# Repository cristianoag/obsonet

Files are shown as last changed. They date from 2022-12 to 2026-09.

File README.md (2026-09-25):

# Obsonet Reloaded
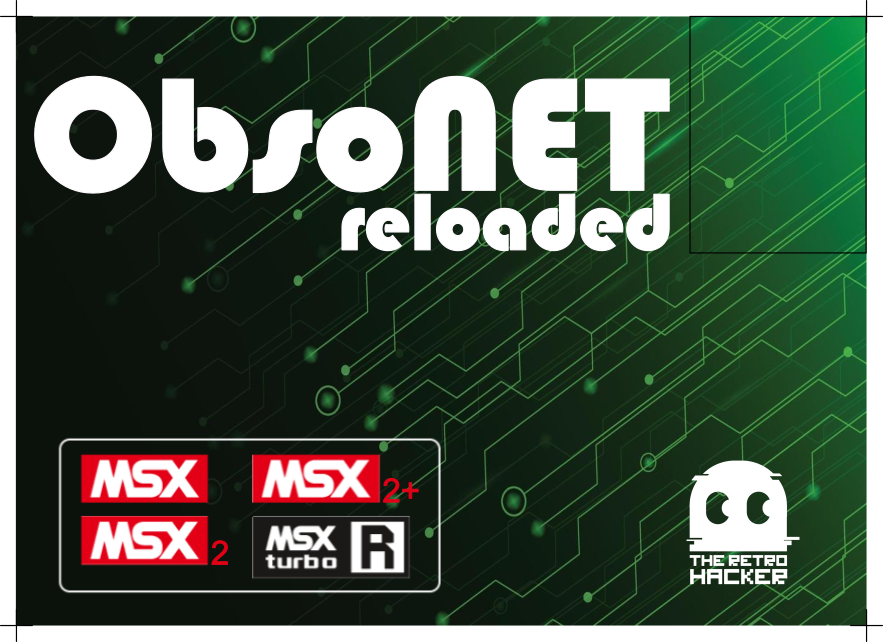
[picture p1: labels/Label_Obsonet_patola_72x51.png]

This is the GitHub repository to host all source files for the Obsonet Reloaded. 

The ObsoNET is the first network card created for the MSX. In 2004, the hardware designer Daniel Berdugo and software developer Nestor Soriano joined forces to create a cartridge to bring ETHERNET standard to the MSX line of computers. 

The cartridge is based on the Realtek RTL8019AS chip and uses a flash memory to host and execute a BIOS that allows the use of network commands from the Nextor operating system (compatible with MSXDOS). An EPROM stores basic configuration data for the RTL8019AS chip and a side connector is used to plug a network cable to your MSX. A GAL16VB is used to implement the logic required to activate and expose the cartridge to the computer.

The original version of the Obsonet was designed to fit a standard Konami cartridge case. The goal of this project is to create a new version of the cartridge that fits the standard Patola cartridge case available in Brazil as well as the standard Konami cases available from multiple vendors WW.

## Hardware 

### PCB

The files required to build the original version of the Obsonet are available [https://github.com/msx-solis/obsonet](here). You can download the gerber files and order from any PCB manufacturer.

I have created another version of the PCB that I called Obsonet Reloaded. The goal was to have the board fitting the standard Patola cartridge cases available in Brazil as well as the standard Konami cases available from multiple vendors WW.

|Front Side|Back Side|
|---|---|
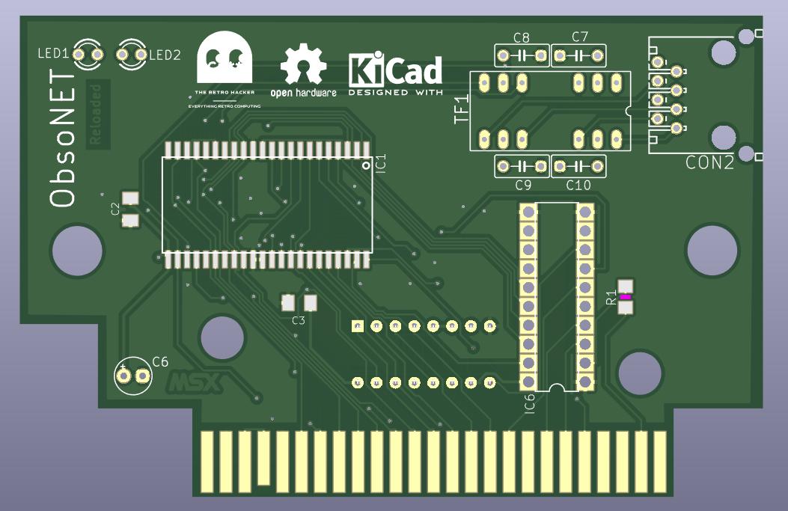
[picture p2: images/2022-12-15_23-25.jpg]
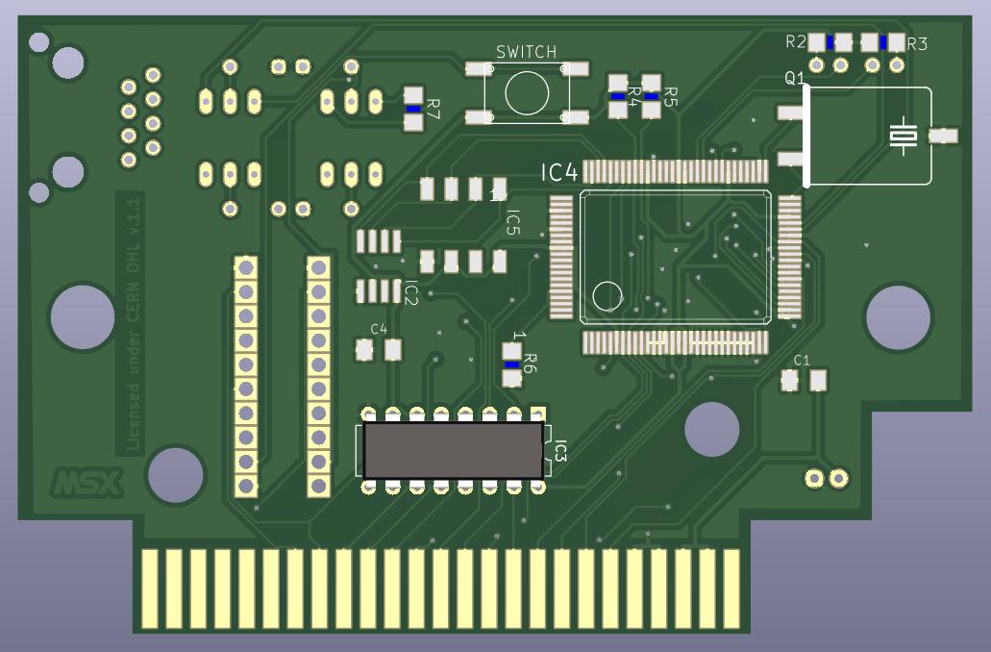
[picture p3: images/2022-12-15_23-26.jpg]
|||
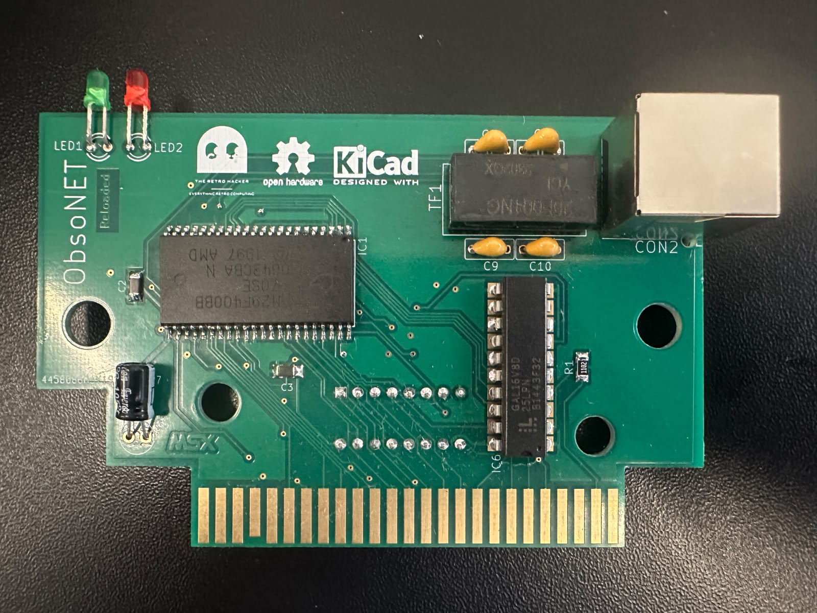
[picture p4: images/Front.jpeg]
Front
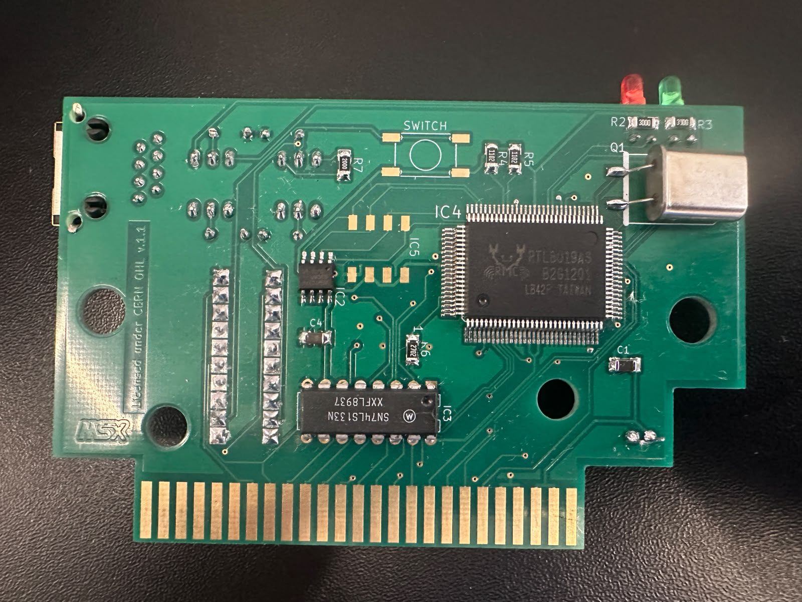
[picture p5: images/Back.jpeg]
Back
|||

### Bill of Materials

[Obsonet Reloaded Interactive BOM](https://htmlpreview.github.io/?https://github.com/cristianoag/obsonet/blob/main/hardware/bom/ibom.html)

| Reference | Value | Description | Package | Qtd | Link |
|---|---|---|---|-----|---|
| C1-C4 | 100nF | C-EUC1206K | C1206 | 4 | [Ali Express](https://s.click.aliexpress.com/e/_DmIukoX) |
| C6 | 100 uF | CPOL-EUE2.5-5 | E2.5-5 | 1 | [Ali Express](https://s.click.aliexpress.com/e/_DmAGIvh) |
| C7-C10 | 10nF | C-EU050-030X075 | C050-030X075 | 4 | [Ali Express](https://s.click.aliexpress.com/e/_Dmqpgbd) |
| CON2 | RJ45_F | 555153-1 | 555153-1 | 1 | [Ali Express](https://s.click.aliexpress.com/e/_c3jkvfpj) |
| IC1 | M29F400M | M29F400M | SO44 | 1 | [Ali Express](https://s.click.aliexpress.com/e/_c3iPiyOp) |
| IC2 | 93C46_SOIC | AT93CX6SOIC08 | SOIC8 (you only need one DIP8 or SOIC8) | 1*  | [Ali Express](https://s.click.aliexpress.com/e/_De08kgX) |
| IC3 | 74LS133  | 74LS133 | DIP16 | 1 | [Ali Express](https://s.click.aliexpress.com/e/_c3DB6u1B) |
| IC4 | RTL8019AS | RTL8019AS | RTL8019AS | 1 | [Ali Express](https://s.click.aliexpress.com/e/_c3tW51wN) |
| IC5 | 93C46_DIL | AT93CX6DIP8 | DIP8 (you only need one DIP8 or SOIC8) | 1*  | |
| IC6 | GAL16V8D | GAL16V8D | DIP20 | 1 | [Ali Express](https://s.click.aliexpress.com/e/_DB7dHhf) |
| LED1 | Green | Led 3mm | LED3MM | 1 | [Ali Express](https://s.click.aliexpress.com/e/_DeGtXFv) |
| LED2 | Orange | Led 3mm | LED3MM | 1 | [Ali Express](https://s.click.aliexpress.com/e/_DeGtXFv) |
| Q1 | 20MHz | HC49GW/HC49U | HC49GW/J (or you can adapt the conventional HC49U) | 1 | [Ali Express](https://s.click.aliexpress.com/e/_c3AIkohX) |
| R1,R4,R5  | 11K | R-EU_R1206 | R1206 | 3 | [Ali Express](https://s.click.aliexpress.com/e/_DF7KTEP) |
| R2,R3 | 300R | R-EU_R1206 | R1206 | 2 | [Ali Express](https://s.click.aliexpress.com/e/_DF7KTEP) |
| R6 | 27K | R-EU_R1206 | R1206 | 1 | [Ali Express](https://s.click.aliexpress.com/e/_DF7KTEP) |
| R7 | 200R | R-EU_R1206 | R1206 | 1 | [Ali Express](https://s.click.aliexpress.com/e/_DF7KTEP) |
| SW1 | SWITCH | Microswitch 6×6 | 6×6 microswitch SMD | 1 | [Ali Express](https://s.click.aliexpress.com/e/_DFJZR15) |
| TF1 | 20F001N  | 20F001N | DIL16/12 | 1 | [Ali Express](https://s.click.aliexpress.com/e/_c3lk5as5) |

## Software

On this repo you can find all software required to build and use the Obsonet Reloaded. There are also binary files with fixes for small issues we found during the project.

### BIOS

The BIOS is the software that runs on the flash memory of the cartridge. It is responsible for initializing the hardware and providing a set of functions to the Nextor operating system.

## Resources

I wrote an article providing more information on how to acquire components and build the new version of the cartridge. You can check it on my blog at [http://www.theretrohacker.com/2022/11/04/the-obsonet-cartridge-for-the-msx/](http://www.theretrohacker.com/2022/11/04/the-obsonet-cartridge-for-the-msx/).

I also have a video in Portuguese showing the board, software, issues we faced during the remodel project as well as showing how to use it to download and use software on your MSX. Please check it at [https://www.youtube.com/watch?v=Ph_3VFheo2I](https://www.youtube.com/watch?v=Ph_3VFheo2I)

## License

Open Hardware

This work is licensed under a [Creative Commons Attribution-NonCommercial-ShareAlike 4.0 International License](http://creativecommons.org/licenses/by-nc-sa/4.0/).

Original version build by Daniel Berdugo and Nestor Soriano. Reloaded version by The Retro Hacker. 

* If you remix, transform, or build upon the material, you must distribute your contributions under the same license as the original.
* You may not use the material for commercial purposes.
* You must give appropriate credit, provide a link to the license, and indicate if changes were made. You may do so in any reasonable manner, but not in any way that suggests the licensor endorses you or your use.

**ATTENTION**

This project was made for the retro community and not for commercial purposes. So only retro hardware forums and individual people can build this project.

THE SALE OF ANY PART OF THIS PROJECT WITHOUT EXPRESS AUTHORIZATION IS PROHIBITED!

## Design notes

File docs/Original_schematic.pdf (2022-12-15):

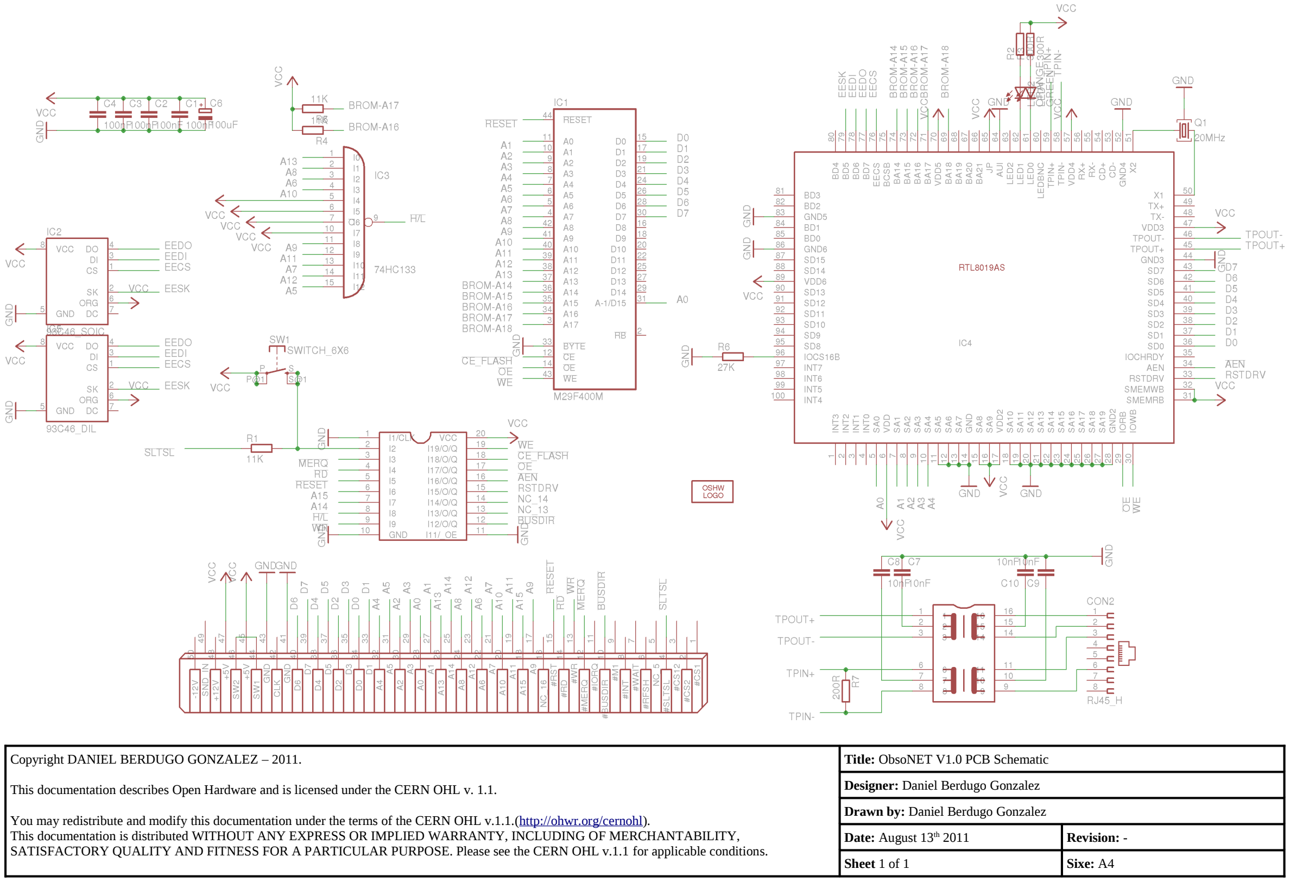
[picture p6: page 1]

Copyright DANIEL BERDUGO GONZALEZ – 2011.

This documentation describes Open Hardware and is licensed under the CERN OHL v. 1.1.

You may redistribute and modify this documentation under the terms of the CERN OHL v.1.1.(http://ohwr.org/cernohl).
This documentation is distributed WITHOUT ANY EXPRESS OR IMPLIED WARRANTY, INCLUDING OF MERCHANTABILITY, SATISFACTORY QUALITY AND FITNESS FOR A PARTICULAR PURPOSE. Please see the CERN OHL v.1.1 for applicable conditions.

Title: ObsoNET V1.0 PCB Schematic Designer: Daniel Berdugo Gonzalez
Drawn by: Daniel Berdugo Gonzalez
Date: August 13th 2011 | Revision: -
Sheet 1 of 1 | Sixe: A4

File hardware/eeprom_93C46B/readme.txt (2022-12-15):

It is mandatory to record 10 bytes in the external eeprom 93C46B to config properly the ethernet controller, so it will be correctly mapped and will be "visible" for MSX.
The first 4 bytes are internal configuration for RTL8019AS (base address mapping, leds, etc... see datasheet), and the following 6 bytes is the mac address.

You can see these values in the attached dump (obsonet_93c46b.bin, obsonet_93c46b.hex).
This example show the mac address 58:53:4D:01:02:03 only for educational purpose, you must modify the example mac addres to match a valid unique mac address wich you can buy to:
  - ieee (I think high quantities).
  - manufacturer like michochip who sells eeproms with preprogrammed macs.
  - reuse the mac address of old unused ethernet cards.

This will ensure every obsonet (and every ethernet card around the world) has its unique mac address, otherwise, 2 or more ethernet cards with the same mac address in the same local network will corrupt communications between them.

You can record the eeprom 93C46B with an external eeprom programmer wich you can find cheap at eBay or Aliexpress.

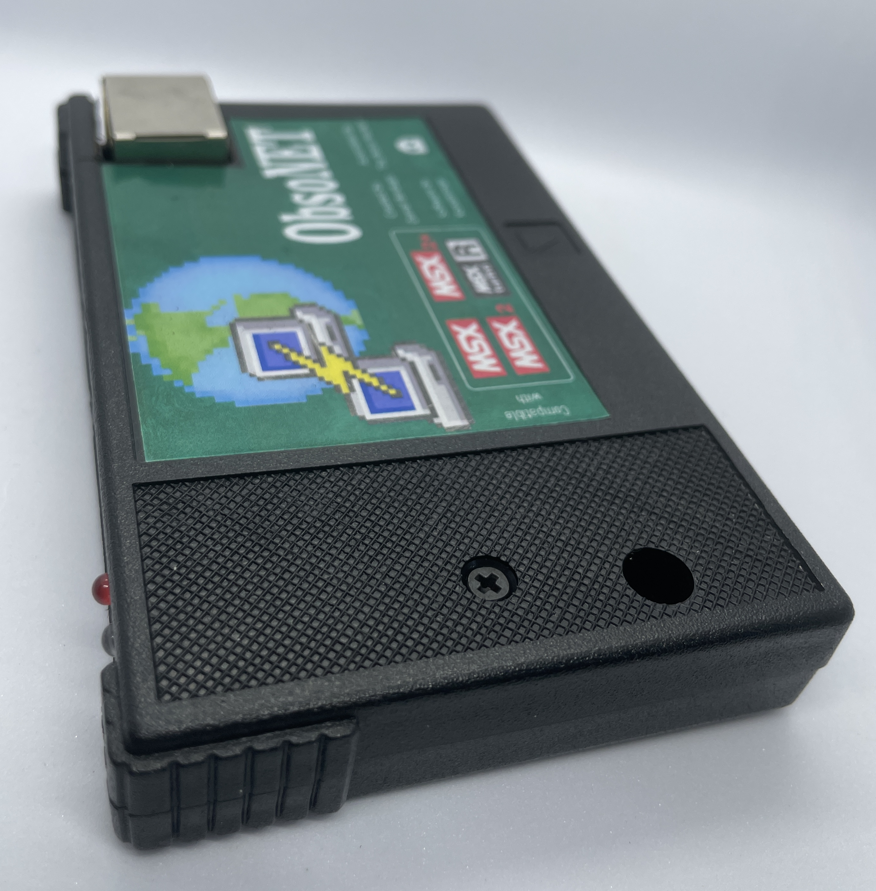
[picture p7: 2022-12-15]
images/20221211_150450807_iOS.jpg

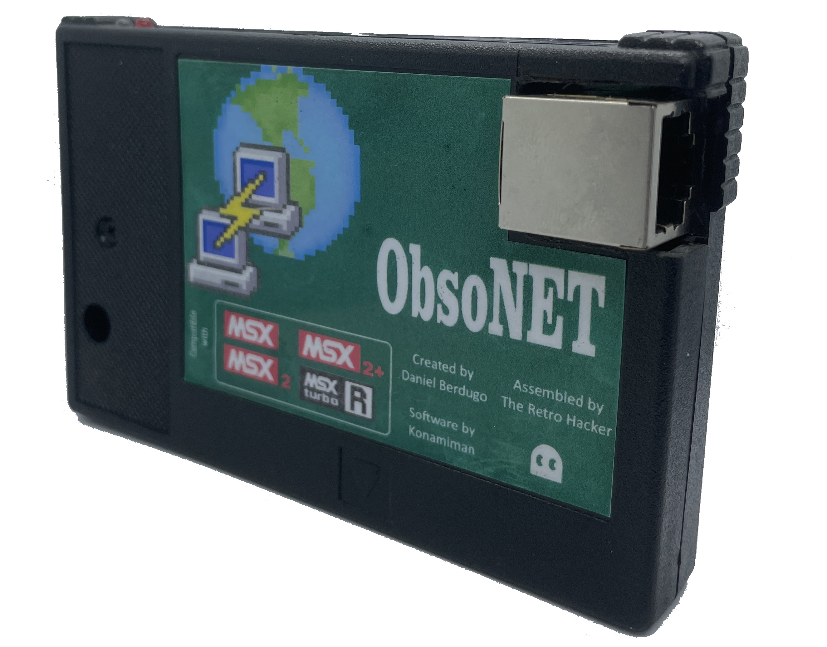
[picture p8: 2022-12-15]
images/20221211_150338708_iOS.jpg

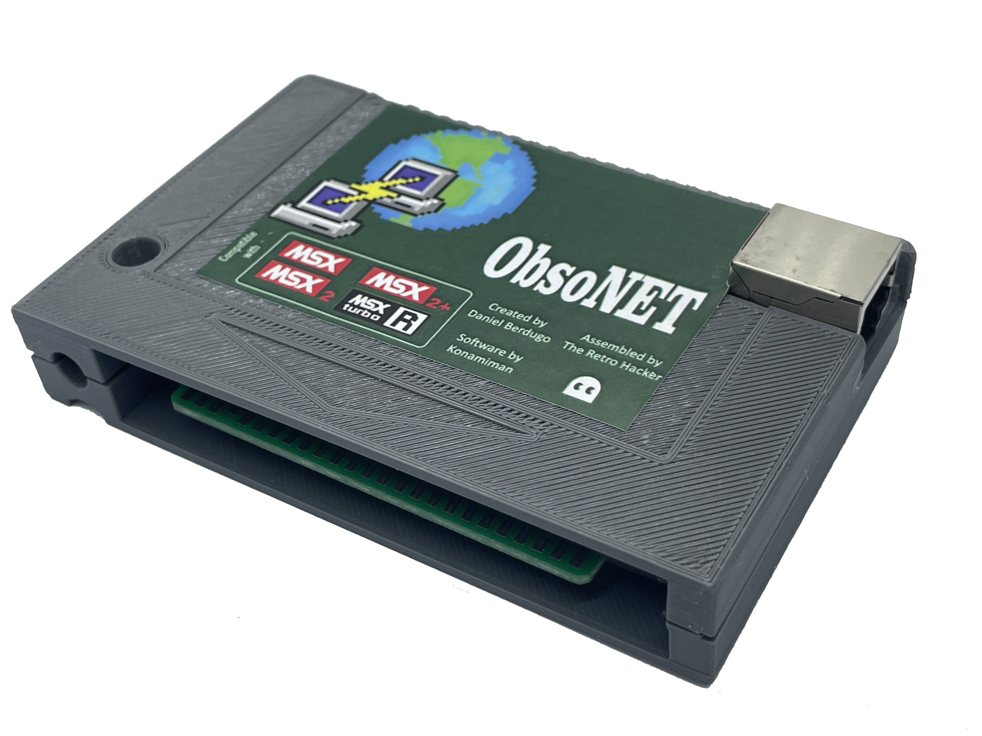
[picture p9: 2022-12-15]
images/_20221104_132002850_iOS_white.jpg

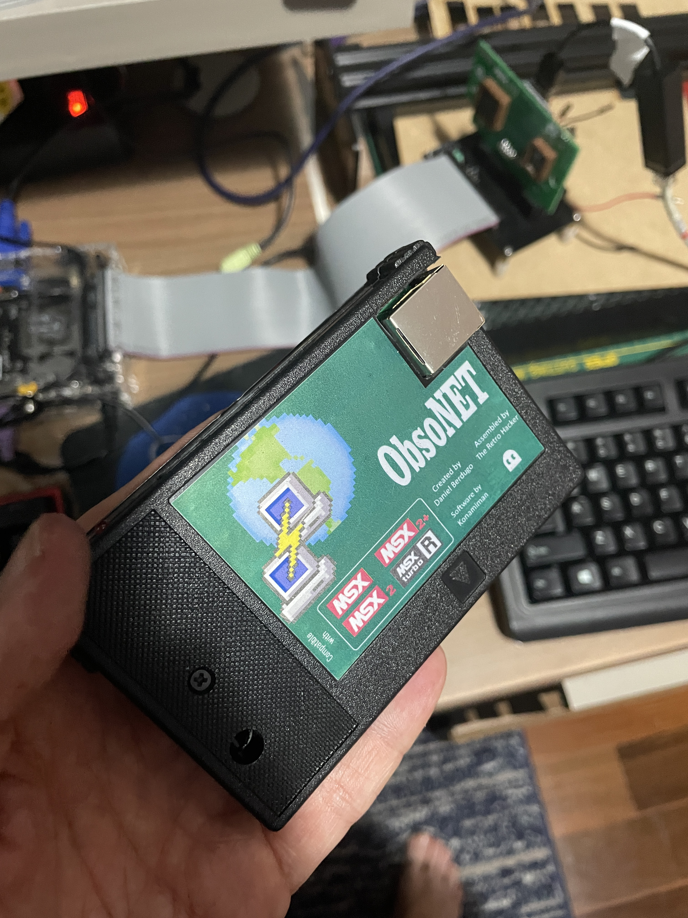
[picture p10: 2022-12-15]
images/20221210_005658216_iOS.jpg

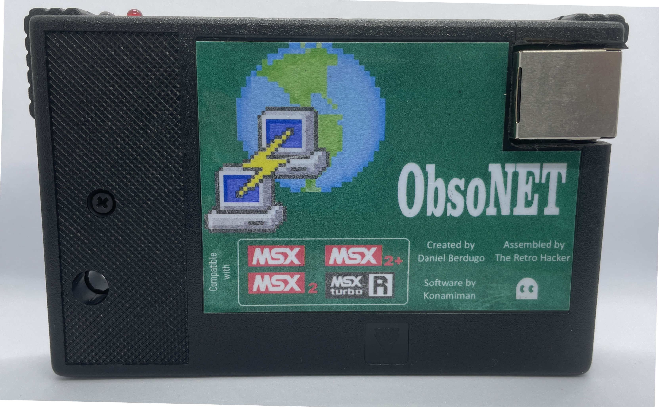
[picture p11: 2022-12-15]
images/20221211_150357282_iOS.jpg

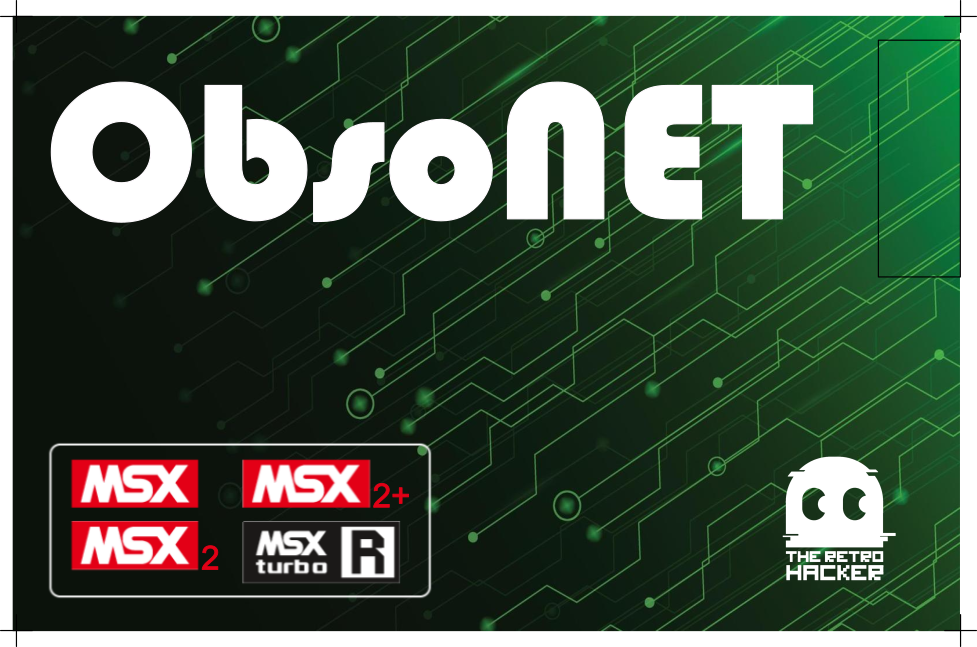
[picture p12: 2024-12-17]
labels/Label_Obsonet_pla_80x52.png

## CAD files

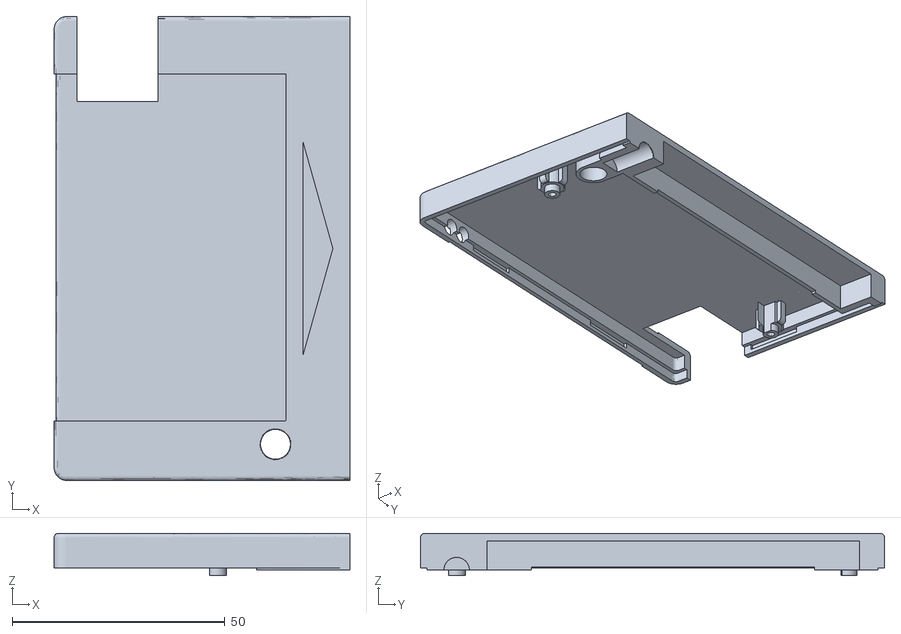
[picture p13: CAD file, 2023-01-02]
case/Obsonet V1 S1.stl
69.5 x 109.0 x 9.95

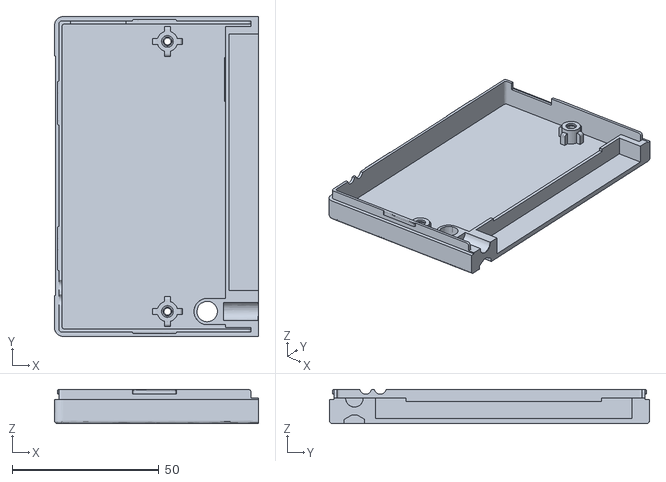
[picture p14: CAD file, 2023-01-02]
case/Obsonet V1 S2.stl
69.5 x 109.0 x 11.6

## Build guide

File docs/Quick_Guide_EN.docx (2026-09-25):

# Obsonet – Quick Guide

The ObsoNET is the first network card built for MSX. In 2004, hardware designer Daniel Berdugo and software developer Nestor Soriano (Konamiman) joined forces to connect their MSX to the Internet.

The cartridge is based on the Realtek RTL8019AS chip and uses flash memory to store a BIOS that allows the use of network commands from the MSXDOS operating system. An EPROM stores basic configuration data for the RTL8019AS chip, and an RJ-45 connector is used to connect a network cable to your MSX.

## Requirements

The following items provide a list of requirements for using Obsonet on your MSX:

1. An MSX computer with at least 128K RAM MAPPER
2. MSX-DOS 1, 2, or Nextor
3. The appropriate variant of INL.COM, the InterNestor Lite installation and control program
4. If you are running MSX-DOS 1: MSR.COM (to install mapper support routines and a UNAPI RAM helper). If you are running MSX-DOS 2 or Nextor: RAMHELPR.COM (installs a UNAPI RAM helper)

The files required to load the TCP/IP stack and the UNAPI ram helper can be obtained from http://tinyurl.com/e9f845bb

## Installing and activating the TCP/IP stack

To use your Obsonet with TCP/IP you need to run a set of scripted commands. These commands can be run from a floppy disk, SDMapper, Carnivore2, MSXUSB, or any other device that allows you to execute commands in an MSX-DOS session.

1. Install the RAM UNAPI helper or the mapper + RAM UNAPI help pack support routines, with "RAMHELPR I" or "MSR I", if you are using MSX-DOS 1.
2. Install InterNestor Lite with "INL2 I". Note that there are two versions in the package. INL.COM and INL2.COM, INL2.COM has a fix to enable better compatibility with more DHCP servers.

Tip: You can combine the above steps and simply run "RAMHELPR I INL2 I" or "MSR I INL2 I ".

## Configuring IP addresses

If there is a DHCP server on your network (which is the most common case when using the operators' Internet access router), you don't need to configure anything, as Internestor (INL) will get all TCP/IP settings automatically.

If you want to configure manually, you must run the following commands:

Inl2 ip d 0

Inl2 ip l <endereço IP>

Inl2 ip m <subnet>

Inl2 ip g <default gateway endereço IP>

Inl2 ip p <primary endereço IP do servidor DNS>

Inl2 ip <secondary DNS server ip endereço IP>

The first command, inl ip d 0, disables the InterNestor DHCP client, to allow manual configuration even on a network with the presence of a DHCP server.

Alternatively, to run these commands sequentially, you can create a BAT or text file containing them (minus the inl at the beginning of each line) called INL. CFG in the same directory as INL2.COM. In this way, InterNestor will read the file and apply the settings from the moment of installation.

Watch the video available athttps://www.youtube.com/watch?v=Ph_3VFheo2I to follow these initial steps and learn a little more about the Obsonet card.

More information about the card and usage:

- InterNestor Lite – Architecture and Limitations - https://github.com/Konamiman/MSX/blob/master/SRC/INL/DOCS/architecture.md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
- InterNestor Lite – Configuration - https://github.com/Konamiman/MSX/blob/master/SRC/INL/DOCS/configuration.md
- InterNestor Lite – Referência dos Comandos - https://github.com/Konamiman/MSX/blob/master/SRC/INL/DOCS/control-program.md
- MSXHUB – Install software directly from Internet using an UNAPI compatible network card - https://msxhub.com/

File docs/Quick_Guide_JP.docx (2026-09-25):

# Obsonet – クイックガイド

ObsoNET は、MSX 向けに開発された最初のネットワークカードです。2004年、ハードウェアデザイナーの Danlel Berdugo 氏とソフトウェア開発者の Nestor Soriano 氏（Konamiman）が協力し、MSXをインターネットに接続しました。

このカートリッジはRealtek RTL8019ASチップを搭載し、フラッシュメモリにBIOSを保存することで、MSXDOS オペレーティングシステムからネットワークコマンドを使用することができます。EPROM には RTL8019AS チップの基本設定データが保存されており、RJ-45コネクタはネットワークケーブルをMSXに接続するために使用します。

## 要件

MSX で Obsonet を使用するための要件は次のとおりです。

1. 128K以上のRAM MAPPERを搭載したMSXコンピュータ
2. MSX-DOS 1, 2またはNextor
3. InterNestor Llteのインストールおよび制御プログラムであるINL.COMの適切なバージョン
4. MSX-DOS 1を使用している場合：MSR.COM（MAPPERサポートルーチンとUNAPI RAMヘルパーをインストールします）。MSX-DOS 2またはNextorを使用している場合：RAMHELPR.COM（UNAPI RAMヘルパーをインストールします）。

TCP/IPスタックとUNAPI RAMヘルパーをロードするために必要なファイルは以下から入手できます
http://tinyurl.com/e9f845bb

## TCP/IPスタックのインストールと有効化

ObsonetをTCP/IPで使用するには、一連のスクリプトコマンドを実行する必要があります。これらのコマンドは、フロッピーディスク、SDMapper、Carnivore2、MSXUSB、またはMSX-DOSセッションでコマンドを実行できるその他のデバイスから実行できます。

1. RAM UNAPIヘルパー、またはマッパー+RAM UNAPIヘルプパックのサポートルーチンを "RAMHELPR I"または"MSR I"とともにインストールします。（MSX DOS 1を使用している場合）
2. InterNestor Liteを"INL2 I"とともにインストールします。パッケージには2つのバージョンがあります。INL.COMとINL2.COMです。INL2.COMには、より多くのDHCPサーバーとの互換性を向上させるためのオプションがあります。

Tip:上記の手順を組み合わせて、"RAMHELPR I INL2 I"または"MSR INL2 I"を実行することもできます

## IPアドレスの設定

ネットワーク上にDHCPサーバーが存在する場合（通信事業者のインターネットアクセスルーターを使用する場合に最も一般的です）、Internetor (lNL) がすべてのTCP/IP設定を自動的に取得するため、何も設定する必要はありません。

手動で設定する場合は、以下のコマンドを実行する必要があります。

inl2 ip d 0

inl2 ip I <デフォルトゲートウェイ IP>

inl2 ip m <サブネット>

inl2 ip g <デフォルトゲートウェイ IP>

inl2 ip p <DNSサーバーのプライマリ IP>

inl2 ip <セカンダリDNSサーバー IP >

最初のコマンド inl ip d 0 は、Internetor DHCPクライアントを無効にし、DHCPサーバーが存在するネットワークでも手動で設定できるようにします。

あるいは、これらのコマンドを順番に実行するには、INL2.COMと同じディレクトリに、各行の先頭の inl を除いたコマンドを含む INL.CFG というBATファイルまたはテキストファイルを作成します。こうすることで、InterNestorはファイルを読み込み、インストール時の設定を適用します。

これらの初期手順とObsonetカードについてさらに詳しく知るには、https://www.youtube.com/watch?v=Ph_3VFheo2I にあるビデオをご覧ください。

カードと使用方法に関する詳細情報：

- InterNestor Lite - アーキテクチャと制限事項 -https://github.com/Konamiman/MSX/blob/master/SRC/INL/DOCS/architecture.md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
- InterNestor Lite - 設定https://github.com/Konamiman/MSX/blob/master/SRC/INL/DOCS/configuration.md
- InterNestor Lite - コマンドリファレンスhttps://github.com/Konamiman/MSX/blob/master/SRC/INL/DOCS/control-program.md
- MSXHUB - UNAPI対応ネットワークカードを使用してインターネットから直接ソフトウェアをインストール – https://msxhub.com/

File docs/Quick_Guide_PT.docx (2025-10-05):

# Obsonet – Manual Rápido de Uso

O ObsoNET é o primeiro cartão de rede criado para o MSX. Em 2004, o designer de hardware Daniel Berdugo e o desenvolvedor de software Nestor Soriano (o Konamiman) uniram forças para permitir conectar o seu MSX a Internet!

O cartucho é baseado no chip Realtek RTL8019AS e usa uma memória flash para armazenar uma BIOS que permite o uso de comandos de rede a partir do sistema operacional MSXDOS. Uma EPROM armazena dados básicos de configuração para o chip RTL8019AS e um conector RJ45 lateral é usado para conectar um cabo de rede ao seu MSX.

## Requisitos

Os itens abaixo fornecem uma lista de requisitos para utilizar a Obsonet no seu MSX:

- Um computador MSX com pelo menos 128K de RAM mapeado
- MSX-DOS 1 ou 2, ou Nextor
- A variante apropriada do INL.COM, o programa de instalação e controle do InterNestor Lite
- Se você estiver executando o MSX-DOS 1: MSR.COM (para instalar rotinas de suporte do mapper e um auxiliar de RAM da UNAPI). Se você estiver executando MSX-DOS 2 ou Nextor: RAMHELPR.COM (instala um auxiliar RAM UNAPI)

Os arquivos necessários para carregamento da pilha TCP/IP e o auxiliar RAM UNAPI podem ser obtidos em http://tinyurl.com/e9f845bb

## Instalaçao e Ativação da Pilha TCP/IP

Para utilizar seu Obsonet com TCP/IP você precisa executar um conjunto de comandos em sequencia. Estes comandos podem ser executados a partir de um disquete, SDMapper, Carnivore2, MSXUSB ou qualquer outro dispositivo que permita executar comandos em uma sessão MSX-DOS.

- Instale o helper RAM unapi ou as rotinas de suporte do mapper + pacote de ajuda RAM UNAPI, com “RAMHELPR I” ou “MSR I”, se você estiver usando MSX-DOS 1.
- Instale o InterNestor Lite com “INL2 I”. Note que no pacote de comandos existem duas versões no INL. INL.COM e INL2.COM, o INL2.COM possui uma correção para permitir melhor compatibilidade com servidores DHCP.

Dica: você pode combinar as etapas acima e simplesmente executar “RAMHELPR I INL2 I” ou “MSR I INL2 I”.

## Configurandor endereços IP

Se existir um servidor DHCP em sua rede (que é o caso mais comum ao usar roteador de acesso à Internet das operadoras), você não precisará configurar nada, uma vez que o Internestor (INL) vai obter todas as configurações TCP/IP automaticamente.

Se quiser configurar manualmente, você precisa executar os seguintes comandos:

Inl2 ip d 0

Inl2 ip l <endereço IP>

Inl2 ip m <subnet>

Inl2 ip g <default gateway endereço IP>

Inl2 ip p <primary endereço IP do servidor DNS>

Inl2 ip <secondary DNS server ip endereço IP>

O primeiro comando, inl ip d 0, desativa o cliente DHCP do InterNestor, para permitir configuração manual mesmo em rede com a presença de um DHP server.

Alternativamente, para executar esses comandos em sequencia, você pode criar um arquivo BAT ou um de texto contendo-os (menos o inl no início de cada linha) chamado INL.CFG no mesmo diretório de INL2.COM. Desta forma, o InterNestor lerá o arquivo e aplicará a configuração a partir do momento da instalação.

Consulte o vídeo disponível em https://www.youtube.com/watch?v=Ph_3VFheo2I para acompanhar estes passos iniciais e aprender um pouco mais sobre o cartão Obsonet.

Mais informações sobre o cartão e uso:

- InterNestor Lite – Architecture and Limitations (em inglês) - https://github.com/Konamiman/MSX/blob/master/SRC/INL/DOCS/architecture.md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
- InterNestor Lite – Configuration (em inglês) - https://github.com/Konamiman/MSX/blob/master/SRC/INL/DOCS/configuration.md
- InterNestor Lite – Referência dos Comandos (em inglês) - https://github.com/Konamiman/MSX/blob/master/SRC/INL/DOCS/control-program.md
- Aplicações básicas de rede implementadas de acordo com a especificaçao TCP/IP UNAPI - https://github.com/Konamiman/MSX/tree/master/SRC/NETWORK
- MSXHUB – Install software directly from Internet using an UNAPI compatible network card - https://msxhub.com/

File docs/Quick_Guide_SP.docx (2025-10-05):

# Obsonet – Manual Rápido de Uso

ObsoNET es la primera tarjeta de red creada para MSX. En 2004, el diseñador de hardware Daniel Berdugo y el desarrollador de software Nestor Soriano (Konamiman) unieron fuerzas para conectar su MSX a Internet.

El cartucho está basado en el chip Realtek RTL8019AS y utiliza memoria flash para almacenar una BIOS que permite el uso de comandos de red desde el sistema operativo MSXDOS. Una EPROM almacena datos básicos de configuración para el chip RTL8019AS, y se utiliza un conector RJ45 lateral para conectar un cable de red a su MSX.

## Requisitos

Los siguientes elementos proporcionan una lista de requisitos para utilizar Obsonet en su MSX:

- Un ordenador MSX con al menos 128K de RAM MAPPER
- MSX-DOS 1 o 2, o Nextor
- La variante apropiada de INL.COM, el programa de instalación y control InterNestor Lite
- Si está ejecutando MSX-DOS 1:MSR.COM ( para instalar rutinas de soporte de mapper y un ayudante de RAM UNAPI). Si está ejecutando MSX-DOS 2 o Nextor: RAMHELPR.COM (instala un auxiliar de RAM UNAPI)

Los archivos necesarios para carga de la pila TCP/IP y el ayudante de ram unapi se pueden obtener en https://1drv.ms/u/s!AnR50DmsM8JwnaYzw_hP_xz385pbkQ?e=fsyXn7

## Instalación y activación de la pila TCP/IP

Para utilizar su Obsonet con TCP/IP es necesario ejecutar un conjunto de comandos en secuencia. Estos comandos se pueden ejecutar desde un disquete, SDMapper, Carnivore2, MSXUSB o cualquier otro dispositivo que le permita ejecutar comandos en una sesión de MSX-DOS.

1. Instale el ayudante de RAM unapi o las rutinas de soporte del mapper + paquete de ayuda de RAM UNAPI, con "RAMHELPR I" o "MSR I", si está utilizando MSX-DOS 1.
2. Instale InterNestor Lite con "INL2 I". Tenga en cuenta que en el paquete de comandos hay dos versiones en INL. INL.COM y INL2.COM, INL2.COM tiene una solución para permitir una mejor compatibilidad con los servidores DHCP.

Consejo: Puede combinar los pasos anteriores y simplemente ejecutar "RAMHELPR I INL 2 I" o "MSR I INL2 I".

## Configuración de direcciones IP

Si hay un servidor DHCP en su red (que es el caso más común cuando se utiliza el enrutador de acceso a Internet de los operadores), no necesita configurar nada, ya que Internestor (INL) obtendrá todas las configuraciones TCP / IP automáticamente.

Si desea configurar manualmente, debe ejecutar los siguientes comandos:

Inl2 ip d 0

Inl2 ip l <endereço IP>

Inl2 ip m <subnet>

Inl2 ip g <default gateway endereço IP>

Inl2 ip p <primary endereço IP do servidor DNS>

Inl2 ip <secondary DNS server ip endereço IP>

El primer comando, inl ip d 0, deshabilita el cliente DHCP de InterNéstor, para permitir la configuración manual incluso en una red con la presencia de un servidor DHP.

Alternativamente, para ejecutar estos comandos secuencialmente, puede crear un archivo BAT o de texto que los contenga (menos el inl al principio de cada línea) llamado INL. CFG en el mismo directorio que INL2.COM. De esta manera, InterNestor leerá el archivo y aplicará la configuración desde el momento de la instalación.

Vea el video disponible en OBSONET - Acessando a Internet com seu MSX - YouTube (https://www.youtube.com/watch?v=Ph_3VFheo2I) para seguir estos pasos iniciales y aprender un poco más sobre la tarjeta Obsonet.

Más información sobre la tarjeta y el uso:

- InterNestor Lite – Architecture and Limitations (em inglês) - MSX/architecture.md at master · Konamiman/MSX (github.com) (https://github.com/Konamiman/MSX/blob/master/SRC/INL/DOCS/architecture.md)
- InterNestor Lite – Configuration (em inglês) - MSX/configuration.md at master · Konamiman/MSX (github.com) (https://github.com/Konamiman/MSX/blob/master/SRC/INL/DOCS/configuration.md)
- InterNestor Lite – Referência dos Comandos (em inglês) - MSX/control-program.md at master · Konamiman/MSX (github.com) (https://github.com/Konamiman/MSX/blob/master/SRC/INL/DOCS/control-program.md)
- Aplicações básicas de rede implementadas de acordo com a especificaçao TCP/IP UNAPI - MSX/SRC/NETWORK at master · Konamiman/MSX (github.com) (https://github.com/Konamiman/MSX/tree/master/SRC/NETWORK)
- MSXHUB – Install software directly from Internet using an UNAPI compatible network card - MSXHub (https://msxhub.com/)

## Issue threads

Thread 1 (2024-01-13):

Disconnected interrupt pin

sdsnatcher, 2024-01-13:
The original obsonet had a design mistake that was corrected in the obsonet2: the interrupt pin was disconnected, resulting in increased latency.

Your design seems to have inherited the same issue.

[Here's the obsonete2 schematics](http://www.caro.su/msx/eth4msx.htm).

cristianoag, 2024-01-13:
Thanks. I will review that and update the project.

Get Outlook for iOS<https://aka.ms/o0ukef>
________________________________
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

cristianoag, 2024-01-14:
I noticed there is an inverter, a diode and a jumper between the pin 4 of the RTL801AS and the /INT signal. Also the board available on Caro's side has the jumper disconnected, that means the pin is disconnect from the /INT signal. I will need to make some tests and evaluate the impact of connecting that signal because the current board just works even without that. I will update the project as soon as I test everything.

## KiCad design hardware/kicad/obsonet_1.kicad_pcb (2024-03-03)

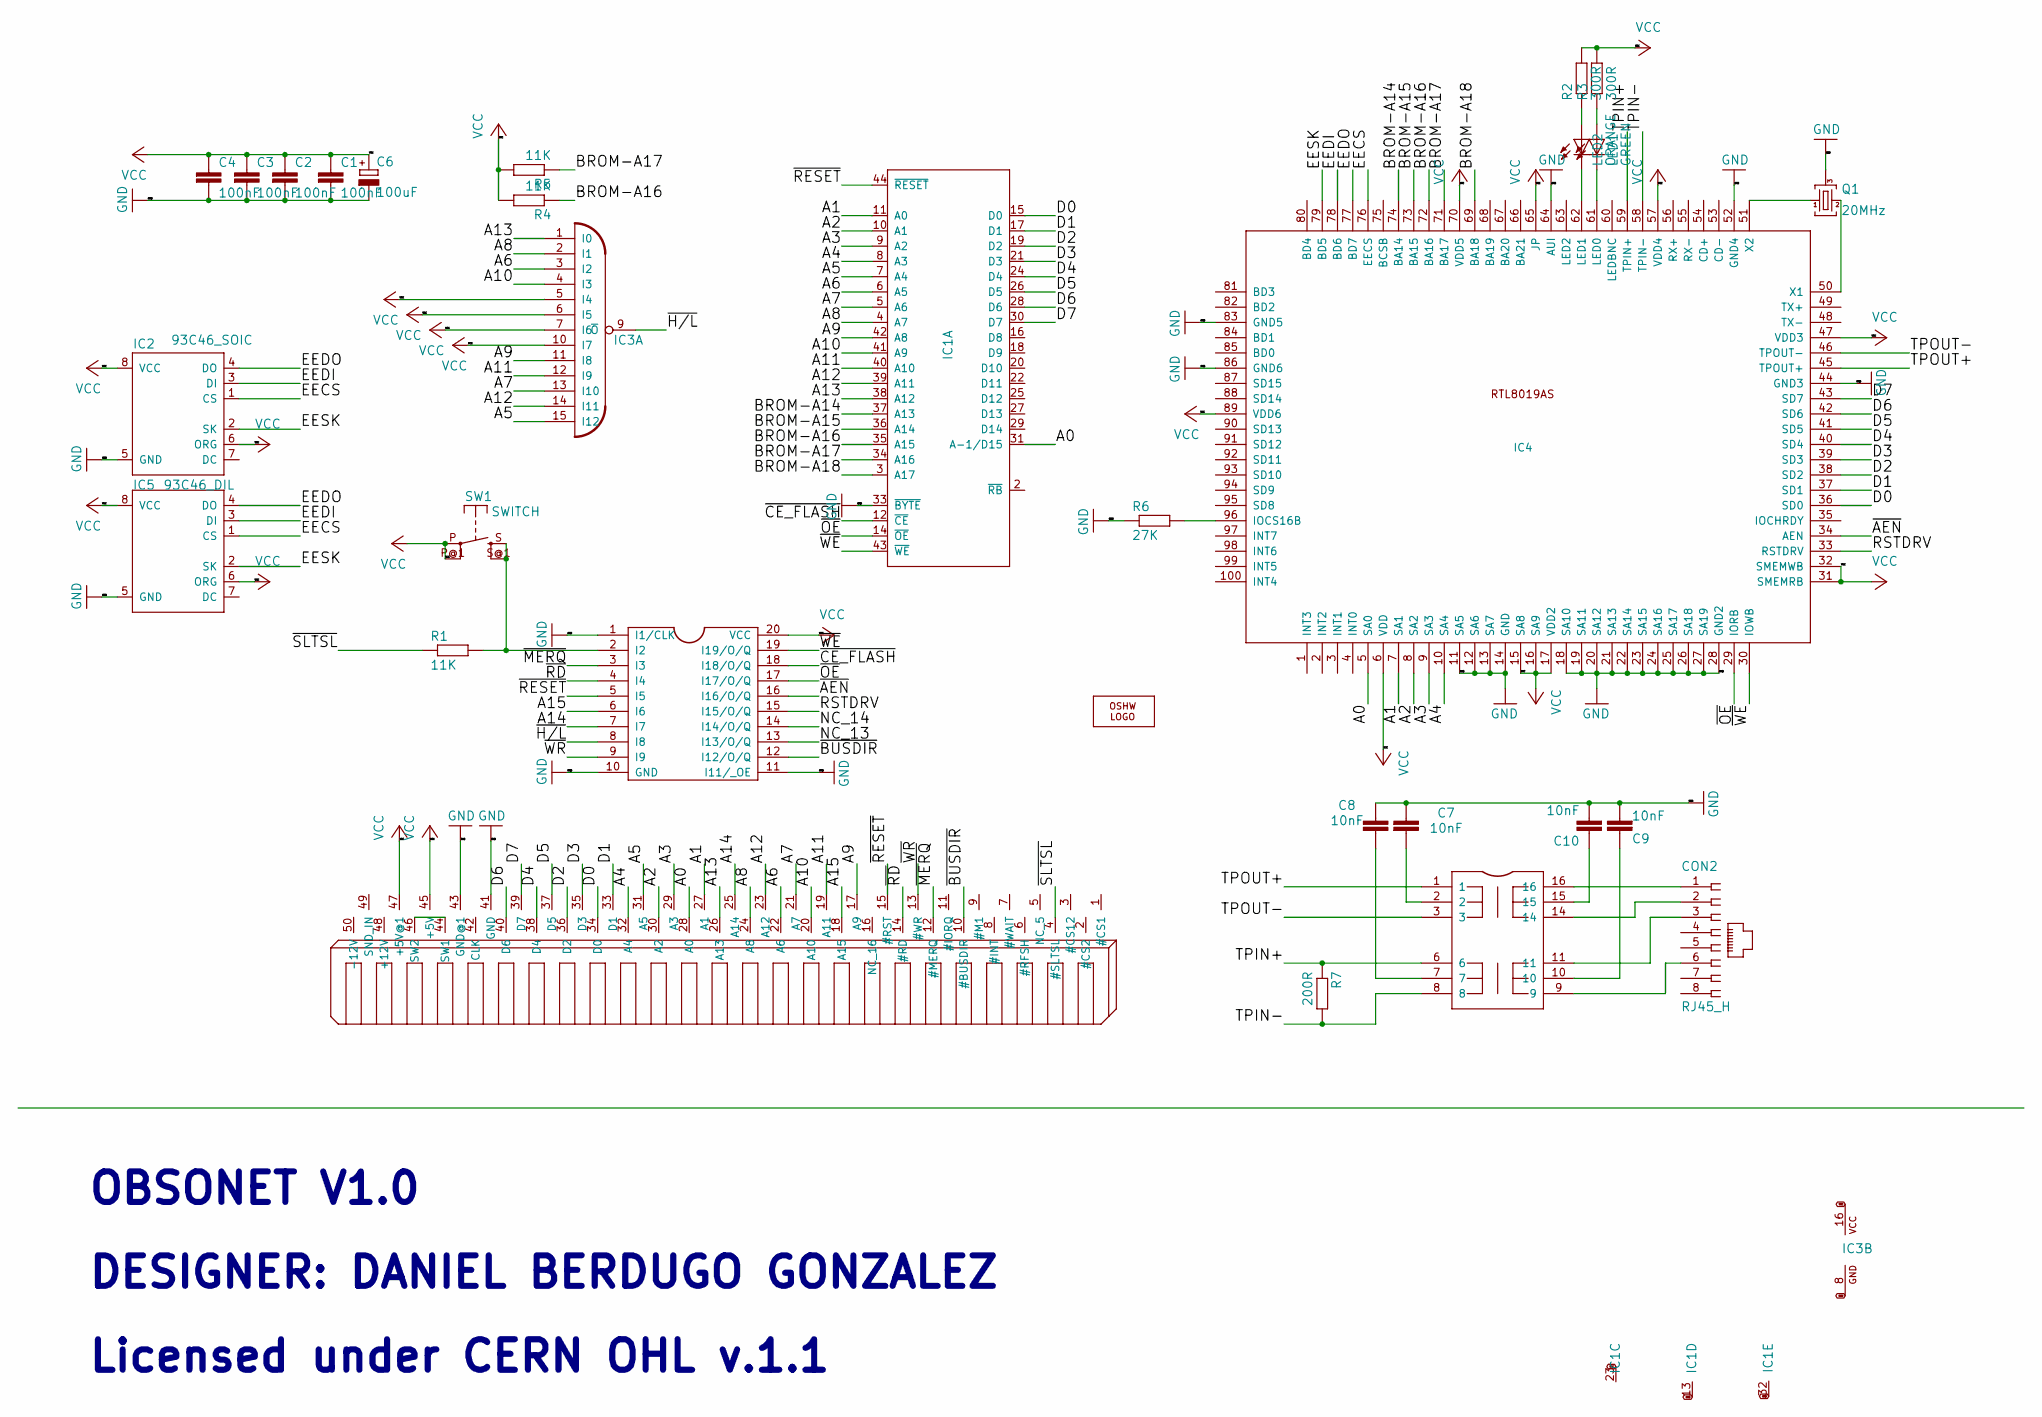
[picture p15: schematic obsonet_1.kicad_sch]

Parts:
C1, C2, C3, C4: 100nF; C1206K
C6: 100uF; E2,5-5
C7, C8, C9, C10: 10nF; C050-030X075
CON1: CART_BOARD; MSXCART
CON2: RJ45_H; 555153-1
IC1: M29F400M; SO44
IC2: 93C46_SOIC; SOIC8
IC3: 74HC133; DIP16
IC4: RTL8019AS
IC5: 93C46_DIL; DIP8
IC6: GAL16V8D; DIL20_SQUARE_1.5MM
LED1: GREEN; LED3MM
LED2: ORANGE; LED3MM
LOGO1: OSHW_LOGO_FILLX0500-NT; OSHW_FILLX500_NOTEXT
Q1: 20MHz; HC49GW
R1, R4, R5: 11K; R1206
R2, R3: 300R; R1206
R6: 27K; R1206
R7: 200R; R1206
SW1: SWITCH; MICROPULSADOR_6X6
TF1: 20F001N; DIL16_12

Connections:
/A0: CON1.28 (A0), IC1.31 (A-1/D15), IC4.5 (SA0)
/A1: CON1.27 (A1), IC1.11 (A0), IC4.7 (SA1)
/A2: CON1.30 (A2), IC1.10 (A1), IC4.8 (SA2)
/A3: CON1.29 (A3), IC1.9 (A2), IC4.9 (SA3)
/A4: CON1.32 (A4), IC1.8 (A3), IC4.10 (SA4)
/A5: CON1.31 (A5), IC1.7 (A4), IC3.15 (I12)
/A6: CON1.22 (A6), IC1.6 (A5), IC3.3 (I2)
/A7: CON1.21 (A7), IC1.5 (A6), IC3.13 (I10)
/A8: CON1.24 (A8), IC1.4 (A7), IC3.2 (I1)
/A9: CON1.17 (A9), IC1.42 (A8), IC3.11 (I8)
/A10: CON1.20 (A10), IC1.41 (A9), IC3.4 (I3)
/A11: CON1.19 (A11), IC1.40 (A10), IC3.12 (I9)
/A12: CON1.23 (A12), IC1.39 (A11), IC3.14 (I11)
/A13: CON1.26 (A13), IC1.38 (A12), IC3.1 (I0)
/A14: CON1.25 (A14), IC6.7 (I7)
/A15: CON1.18 (A15), IC6.6 (I6)
/BROM-A14: IC1.37 (A13), IC4.74 (BA14)
/BROM-A15: IC1.36 (A14), IC4.73 (BA15)
/BROM-A16: IC1.35 (A15), IC4.72 (BA16), R4.1
/BROM-A17: IC1.34 (A16), IC4.71 (BA17), R5.1
/BROM-A18: IC1.3 (A17), IC4.69 (BA18)
/D0: CON1.34 (D0), IC1.15 (D0), IC4.36 (SD0)
/D1: CON1.33 (D1), IC1.17 (D1), IC4.37 (SD1)
/D2: CON1.36 (D2), IC1.19 (D2), IC4.38 (SD2)
/D3: CON1.35 (D3), IC1.21 (D3), IC4.39 (SD3)
/D4: CON1.38 (D4), IC1.24 (D4), IC4.40 (SD4)
/D5: CON1.37 (D5), IC1.26 (D5), IC4.41 (SD5)
/D6: CON1.40 (D6), IC1.28 (D6), IC4.42 (SD6)
/D7: CON1.39 (D7), IC1.30 (D7), IC4.43 (SD7)
/EECS: IC2.1 (CS), IC4.76 (EECS), IC5.1 (CS)
/EEDI: IC2.3 (DI), IC4.78 (BD6), IC5.3 (DI)
/EEDO: IC2.4 (DO), IC4.77 (BD7), IC5.4 (DO)
/EESK: IC2.2 (SK), IC4.79 (BD5), IC5.2 (SK)
/NC_13: IC6.13 (I13/O/Q)
/NC_14: IC6.14 (I14/O/Q)
/RSTDRV: IC4.33 (RSTDRV), IC6.15 (I15/O/Q)
/TPIN+: IC4.59 (TPIN+), R7.1, TF1.6
/TPIN-: IC4.58 (TPIN-), R7.2, TF1.8
/TPOUT+: IC4.45 (TPOUT+), TF1.1
/TPOUT-: IC4.46 (TPOUT-), TF1.3
/~AEN: IC4.34 (AEN), IC6.16 (I16/O/Q)
/~BUSDIR: CON1.10 (#BUSDIR), IC6.12 (I12/O/Q)
/~CE_FLASH: IC1.12 (~CE), IC6.18 (I18/O/Q)
/~H/L: IC3.9 (~O), IC6.8 (I8)
/~MERQ: CON1.12 (#MERQ), IC6.3 (I3)
/~OE: IC1.14 (~OE), IC4.29 (IORB), IC6.17 (I17/O/Q)
/~RD: CON1.14 (#RD), IC6.4 (I4)
/~RESET: CON1.15 (#RST), IC1.44 (~RESET), IC6.5 (I5)
/~SLTSL: CON1.4 (#SLTSL), R1.1
/~WE: IC1.43 (~WE), IC4.30 (IOWB), IC6.19 (I19/O/Q)
/~WR: CON1.13 (#WR), IC6.9 (I9)
GND: C1.2, C2.2, C3.2, C4.2, C6.-, C7.1, C8.1, C9.2, C10.2, CON1.41 (GND), CON1.43 (GND@1), IC1.13 (GND), IC1.32 (GND), IC1.33 (~BYTE), IC2.5 (GND), IC3.8 (GND), IC4.11 (SA5), IC4.12 (SA6), IC4.13 (SA7), IC4.14 (GND), IC4.18 (SA10), IC4.19 (SA11), IC4.20 (SA12), IC4.21 (SA13), IC4.22 (SA14), IC4.23 (SA15), IC4.24 (SA16), IC4.25 (SA17), IC4.26 (SA18), IC4.27 (SA19), IC4.28 (GND2), IC4.44 (GND3), IC4.52 (GND4), IC4.64 (AUI), IC4.83 (GND5), IC4.86 (GND6), IC5.5 (GND), IC6.1 (I1/CLK), IC6.10 (GND), IC6.11 (I11/_OE), Q1.3, R6.1
unnamed: C7.2, TF1.2
unnamed: C8.2, TF1.7
unnamed: C9.1, TF1.10
unnamed: C10.1, TF1.15
unnamed: CON1.44 (SW1), CON1.46 (SW2)
unnamed: CON2.1, TF1.16
unnamed: CON2.2, TF1.14
unnamed: CON2.3, TF1.11
unnamed: CON2.6, TF1.9
unnamed: IC4.50 (X1), Q1.2
unnamed: IC4.51 (X2), Q1.1
unnamed: IC4.61 (LED0), LED1.K (C)
unnamed: IC4.62 (LED1), LED2.K (C)
unnamed: IC4.96 (IOCS16B), R6.2
unnamed: IC6.2 (I2), R1.2, SW1.S, SW1.S@1
unnamed: LED1.A, R3.1
unnamed: LED2.A, R2.1
VCC: C1.1, C2.1, C3.1, C4.1, C6.+, CON1.45 (+5V), CON1.47 (+5V@1), IC1.23 (VCC), IC2.6 (ORG), IC2.8 (VCC), IC3.5 (I4), IC3.6 (I5), IC3.7 (I6), IC3.10 (I7), IC3.16 (VCC), IC4.6 (VDD), IC4.15 (SA8), IC4.16 (SA9), IC4.17 (VDD2), IC4.31 (SMEMRB), IC4.32 (SMEMWB), IC4.47 (VDD3), IC4.57 (VDD4), IC4.65 (JP), IC4.70 (VDD5), IC4.89 (VDD6), IC5.6 (ORG), IC5.8 (VCC), IC6.20 (VCC), R2.2, R3.2, R4.2, R5.2, SW1.P, SW1.P@1

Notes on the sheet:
DESIGNER: DANIEL BERDUGO GONZALEZ
OBSONET V1.0
Licensed under CERN OHL v.1.1

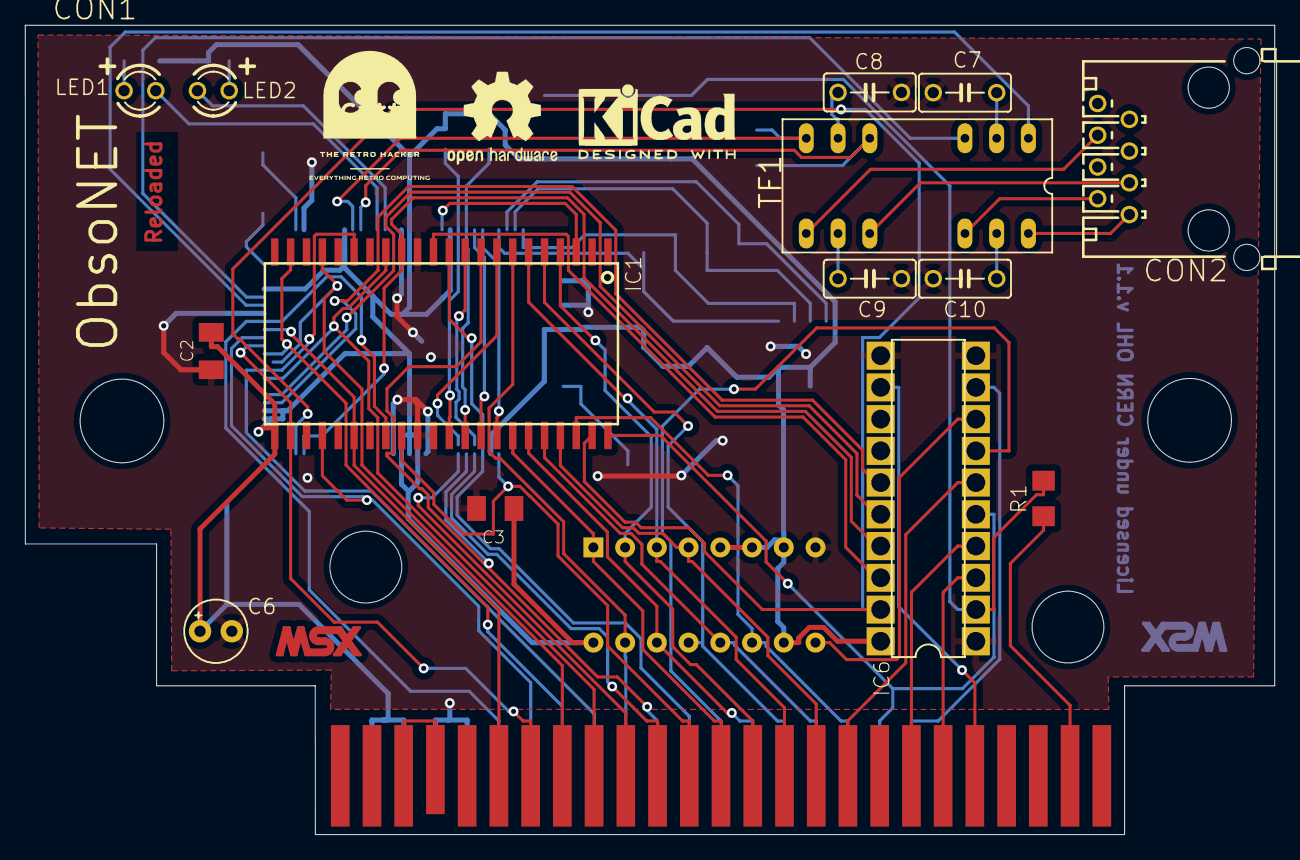
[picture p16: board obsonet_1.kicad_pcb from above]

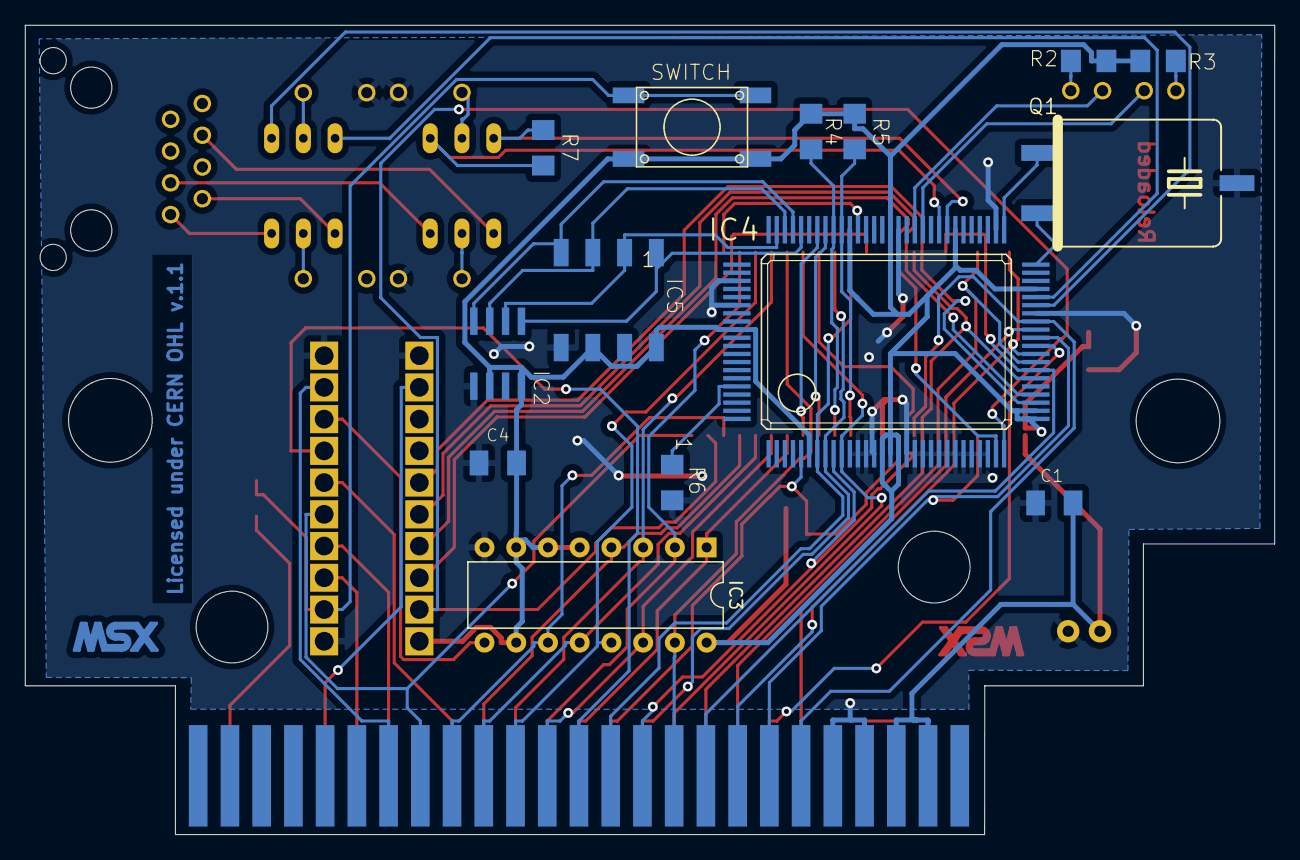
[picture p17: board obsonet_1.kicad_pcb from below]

Board: 2 copper layers, 100.0 x 64.8 mm, 32 parts (15 on the bottom side), 68 nets.

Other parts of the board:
U$1, U$2: LOGO_MSX
U$4: LOGO_OBSONET

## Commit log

2022-12-15 Initial load
    [obsonet_1-B_Mask.gbr, obsonet_1-B_Silkscreen.gbr, obsonet_1-Bottom.gbr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]
2023-01-02 including 3d printer cases
    [Obsonet V1 S1.stl, Obsonet V1 S2.stl]
2024-03-03 Updated licensing and README
    [obsonet_1.kicad_pcb, obsonet_1.kicad_sch]
2024-12-17 new labels, readme.md update, hardware folder organization
    [obsonet_1-B_Mask.gbr, obsonet_1-B_Silkscreen.gbr, obsonet_1-Bottom.gbr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]
2026-09-25 Fixing AliExpress expired links and adding pictures of the assembled board
